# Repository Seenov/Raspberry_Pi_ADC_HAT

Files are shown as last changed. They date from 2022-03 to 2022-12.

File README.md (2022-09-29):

# 6 Channel ADC Hat for Raspberry Pi
Wi-Fi hat with ESP32

For the Raspberry Pi install node-red with version 16 of Nodejs and upload the flow file  "ADC1-esp32c3rev3_2.json" in this root directory. 
The flow file  "ADC1-esp32c3rev3_1.json" works with networks of 512 ip addresses. x.x.0.0 to x.x.1.255 Comment-out line 15 of the "set broadcast ip" node to work with networks of 255 ip addresses.
The list of dependencies for this project are in the file "packages.json"

For Arduino use the sketch in the directory  "RPI_ADC_Hat_analognwifi_rev1"
In the root directory the file "esp32c3setup arduino" show the setting under Tools in the arduino IDE (1.8.16)
The ino file rev2 introduces a self-test feature we use to ensure each unit is functionning properly. DO NOT USE THIS VERSION
The .ino file rev3 is used to test communications with a python script. There is an issue with UDP port usage with this version. It transmitts its messages on port 50450 instead of 5045. It listens on port 5044.

<b>Documentation</b>

<a href="https://seenov.com/2022/03/14/getting_started_6_channel_esp32c3_adc/"><b>Getting </b><b>S</b><b>tarted</b></a>

<a href="https://seenov.com/wp-content/uploads/2022/03/ESP32C3-ADC-hat-specifications.pdf">Specifications</a>

<a href="https://seenov.com/2021/12/15/raspberry-pi-adc-esp32-hat-incredibly-measures-%C2%B112v-with-great-accuracy/">Configuring ADC inputs</a>

<b>Explainer videos Seenov YouTube channel</b>

<a href="https://www.youtube.com/channel/UC92-OhJZzrrUEJLgdM26cIA"> Seenov YouTube Channel</a>

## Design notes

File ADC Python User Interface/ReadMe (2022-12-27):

#################   INSTRUCTIONS  #################
Required files (all in same directory):
ADC_UI_Beta1.py
MQueues.py
_support_Beta1.py
Threads.py

Install CustomTkInter  link: https://github.com/TomSchimansky/CustomTkinter
pip3 install customtkinter
A copy of the customtkinter folder from the Github repository is placed in the 
same folder as this script in case you cannot use pip3

-  Connect power to the  ESP32C3 ADC Hat and wait for the Green LED to turn on.
-  The ADC will be in Hotspot mode. Using a WiFi enabled device, phone, tablet
   or Raspberry Pi. Connect to the Network ADC_xxx, xxx is part of the mac address
   of the ADC. Ignore no Internet messages.
-  Navigate to the Page 192.168.4.1  and enter the SSID and Password of your WiFi
-  The ADC will reboot and the green LED will turn off. If not, retry the previous steps.
-  Run the ADC_UI_Beta1.py python script. A control panel window will open in the center of the screen.
-  The scrit should find the ADC. Enable the ADC channels and you should see the voltages
   being displayed.
   
- Known issues: at startup ADC ch 0 may display a previous value instead of 0 mV
                Sliders are not very responsive on Raspberry PI computers.
                The Seenov Logo is not displayed

-  Find more information at www.seenov.com
-  email us at info@seenov.com for support.

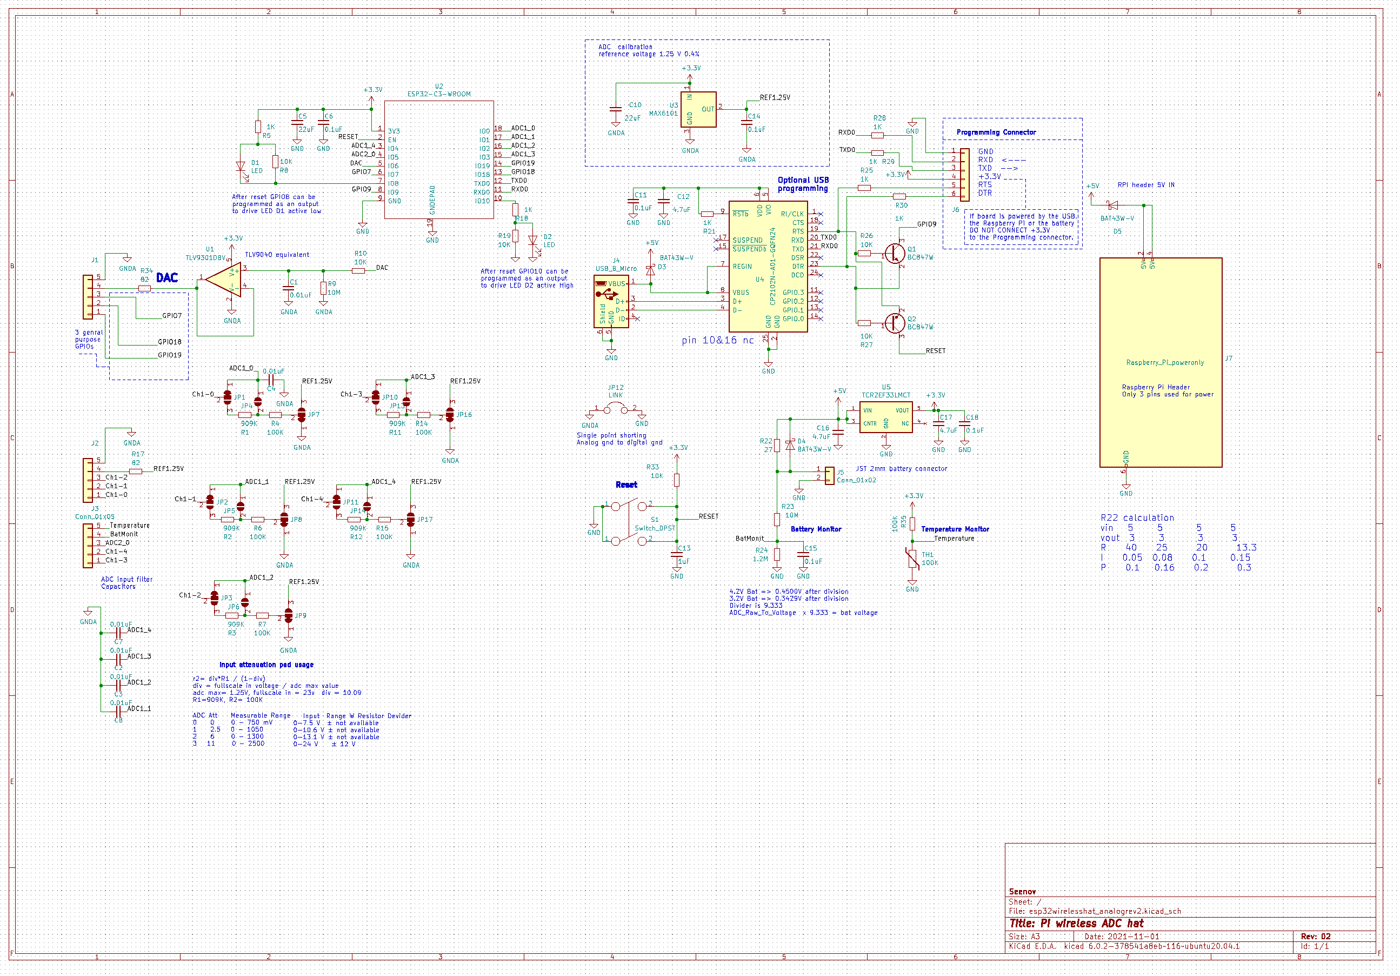
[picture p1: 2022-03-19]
ESP32C3 Raspberry Pi 6 channel ADC Hat Schematicv2.png

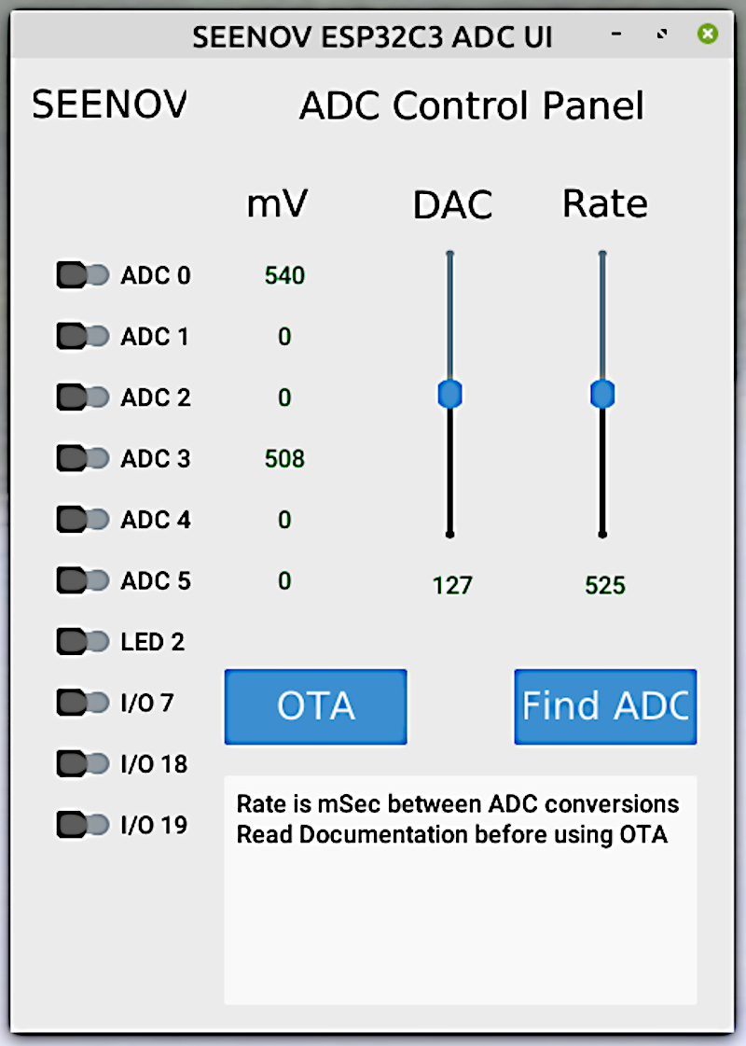
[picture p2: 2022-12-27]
ADC Python User Interface/ADC Python UI1.png

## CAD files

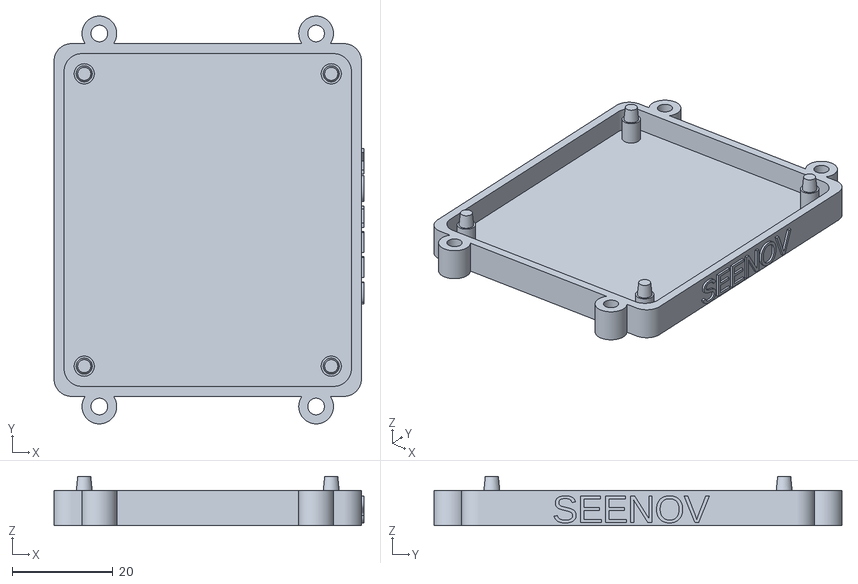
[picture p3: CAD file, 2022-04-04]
OpenScad 3D models/esp32ADC_opencase.stl
61.5 x 80.9 x 9.78

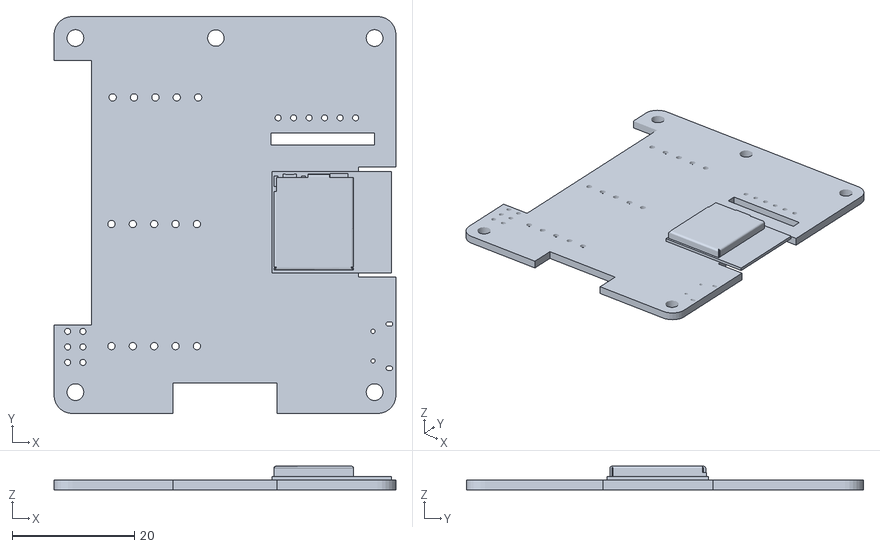
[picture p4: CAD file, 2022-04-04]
OpenScad 3D models/adc.stl
56.0 x 65.0 x 3.93

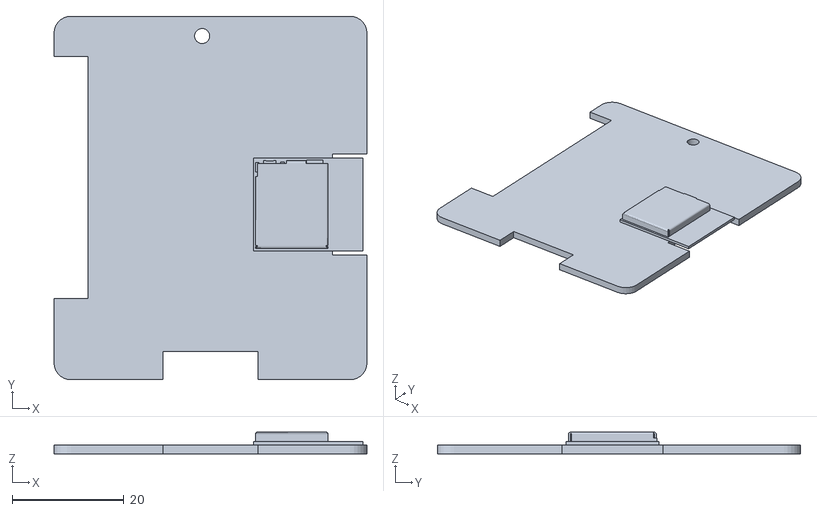
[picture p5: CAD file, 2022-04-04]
OpenScad 3D models/adc2a.stl
56.0 x 65.0 x 3.93

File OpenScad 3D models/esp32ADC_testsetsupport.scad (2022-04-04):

$fn=90;
//include <threads.scad>;
include </home/claudea2/Dropbox/3D printer/openscad_primitives-master/fillet_cube.scad>;
// rev 4 2 slots, 3.5mm instead of 5mm long
overlap =5;
len2 = 10;
len3= 5.16;
len4= 8.9;
diam1= (3.7*25.4)+2.4;
diam2= 5*25.4;  //  was 6*25.4;
ventholesdiam =3;
diam3= 13.6;
diam4= 9.6;
glassdiam=200;
fandiam=120;
largewall=3.2;
smallwall = 1.6;
 baseholediam= 6;
totallen = 104.6;
 pindiam=1.65;  // pogo pin holder diampindiam 1.3 bump 1.5
  wirechannel=1.6;
pcbwidth=40.5;
offx=65;
offy=93.6;
coin1x= -16.9;
coin1y = -65.47;
coin2x= 49;
coin2y = 0;
coin3x= 49;
coin3y = -58;
coin4x=  0;
coin4y= -58;
adcx=56.02  ;
adcy= 65.03;
pin=2.75; //  mounting hole in pcb
pogo1x=-1.27;  //2.54mmx2
pogo1y=4.87;
pogo2x=5.9;  // 3.5mm
pogo2y=7.53;
pogo3x=5.9;
pogo3y=27.53;
pogo4x=6.1;
pogo4y=48.28;
pogo5x=33.2; // 2.54mm
pogo5y=44.93;
screwhole= 3.0;
// pogo IDI   R-1-SC/RSS-75-SC
// receptacle  S-1-E-3.8-G


pogoheight = 6.59 +2.5;
pcbsspacer = 8.64+4.57-1.78-5; // 11.43
pcbheight=178;
pcbthick= 1.6;
//height above PCB
height4= pogoheight+pcbthick;
// for test add 10mm    
len1 = 10 + totallen - len2 -len3 -len4 +overlap;
 fit=0.6; 
mountingspherediam=3;
// measuring tool
//translate([52.5,0,-26]) cube([1,105,1],center=true);
//show = 0;
//show="PCBClips"; // ,   "    " ,       "    ";// "fan";
//show="mount";  // hanging mount
//show="topbox";
//show = "fan";
//show = "PCBBaseclip";

// uncomment to see

//selector ="main";
//selector ="base";

//selector ="push";
//selector = "bolt";
//selector = "tb";
//selector ="break";
selector = "case";
/*********************************************************
*
*        Pogo test jig for ADC rev 2
*
*
**************************************************************/



//color( "Aqua", 1.0 )translate([offx+coin1x,coin1y-offy,pcbsspacer])  import("adc.stl", convexity=3);
module mainpin(){
 // main body above z=0
difference(){
// base cube    
translate([-8,-8,0])  cube([67,75,5]) ;
    
 // larger cut-out for better fit 
translate([-6,-6,-0.05])  cube([adcx+6,adcy+6,8.1]) ;
}
// round corner for better printing
  translate([-6,-6,-7.9])   cylinder(d=8,h=13-0.1);
translate([adcx,-6,-7.9])   cylinder(d=8,h=13-0.1);
translate([-6,+adcy,-7.9])   cylinder(d=8,h=13-0.1);
translate([adcx,+adcy,-7.9])   cylinder(d=8,h=13-0.1);
// space for align pins pcb at correct height
translate([0,0,-0.1]) alignpins(4,4,pcbsspacer);
// Align pins
translate([0,0,pcbsspacer-0.1]) alignpins(2.4,2,4.5);
// base pogo receptacle fit into base
difference(){
translate([-8,-8,-7.9])  cube([67,75,8]) ;
 translate([0,0,-8])    pinholes(10);
}
// align pins
module alignpins(dd1,dd2,hh){
translate([0,0,0])   cylinder(d1=dd1,d2=dd2,h=hh);
translate([coin2x,coin2y,0])  cylinder(d1=dd1,d2=dd2,h=hh);
translate([coin3x,-coin3y,0])  cylinder(d1=dd1,d2=dd2,h=hh);
translate([coin4x,-coin4y,0])  cylinder(d1=dd1,d2=dd2,h=hh);
}
module pinholes(hh){
for(yi =[pogo1y:5.08:pogo1y+5.08]) translate([pogo1x,yi,0]) cylinder(d=pindiam,h=hh);
for(xi =[pogo5x:2.54:pogo5x+(5*2.54)]) translate([xi,pogo5y,0]) cylinder(d=pindiam,h=hh);
    
for(xi =[pogo2x:3.5:pogo2x+(4*3.5)]) translate([xi,pogo2y,0]) cylinder(d=pindiam,h=hh);
for(xi =[pogo3x:3.5:pogo3x+(4*3.5)]) translate([xi,pogo3y,0]) cylinder(d=pindiam,h=hh);
for(xi =[pogo4x:3.5:pogo4x+(4*3.5)]) translate([xi,pogo4y,0]) cylinder(d=pindiam,h=hh);
}
 
}
module base2(){
// bottom base
translate([0,0,15])difference(){
translate([-8-4,-8-4,-40])  cube([67+8,75+8,25]) ;
translate([-8,-8,-40+4])  cube([67,75,30]) ;
translate([-6-33/2,-6-34/2,-41])   cube([33,34,30]);
translate([adcx-33/2,-6-34/2,-41])   cube([33,34,30]);
translate([-6-33/2,+adcy-34/2,-41])   cube([33,34,30]);
translate([adcx-33/2,+adcy-34/2,-41])   cube([33,34,30]);
}
// holder for pushdown
translate([-55,18,-25])  cube([44,25,10]) ;
difference(){
translate([-55,30,-25])  cube([12,12,35]) ;
translate([-46,50,6]) rotate([90,0,0])   cylinder(d=screwhole+0.3, h=50);  
translate([-52,50,6]) rotate([90,0,0])   cylinder(d=screwhole+0.3, h=50);      
}
// tye point spring
difference(){
translate([-25,24,-25])  cube([8,6,15]) ;
translate([-21,50,-12.5]) rotate([90,0,0])   cylinder(d=screwhole, h=50);  
}     
}


if (selector =="main"){
difference(){
      mainpin();
     translate([26,79,-4]) rotate([90,0,0])   cylinder(d=screwhole, h=100);
     translate([-26,-6+79/2,-4]) rotate([90,0,90])   cylinder(d=screwhole, h=100);
  
}
}

if (selector =="base"){
difference(){
      base2();
     translate([26,79,-4]) rotate([90,0,0])   cylinder(d=screwhole+0.5, h=100);
     translate([-26,-6+79/2,-4]) rotate([90,0,90])   cylinder(d=screwhole+0.5, h=100);
  
}
}
if (selector =="push"){

pushdown();
}
// push down
module pushdown(){
 translate([-11,0,0])difference(){
 translate([0,0,0]) rotate([0,0,0])   cylinder(d=76, h=10);
 translate([0,0,-0.1]) rotate([0,0,0])   cylinder(d=61, h=11);
  translate([0,-25,5.5])  cube([100,50,12],center=true);   
    translate([-34,4,-1]) rotate([0,0,0])   cylinder(d=screwhole+0.3, h=20);
    
}
 // lever
    translate([-20,8,0]) rotate([0,0,-2])   cube([150,25,10]);  
}


// bolt holder
if (selector =="bolt"){
    bolt();
}

/******************************************************
*
*   replace a centered square cube with a rounded cube
*
*
************************************************************/
module roundedcube(xx,yy,zz,rr){
    translate([(-xx+(2*rr))/2,(-yy+(2*rr))/2,-zz/2]) minkowski()
{
  cube([xx-(2*rr),yy-(2*rr),zz-1]);
  cylinder(r=rr,h=1);
}
}

if (selector =="break"){
    difference(){
         cube([30,20,12],center=true); 
        translate([0,0,6-2.4])   cube([54,2,5],center=true); 
    }
    translate([0,0,-50-5.5])     cylinder(d=20, h=50);
}


module bolt(){
    
 /*  translate([-(58-2)/2,-(28-2)/2,-5]) minkowski()
{
  cube([60-4,30-4,10-1]);
  cylinder(r=2,h=1);
}
*/
    difference(){
         roundedcube(60,30,10,2); 
        translate([0,0,-0.1])   cube([10.5,10.5,12],center=true);  
        translate([0,0,-0.1])     cylinder(d=22, h=6.5);
        translate([30-6,15-6,-7])     cylinder(d=4, h=14);
        translate([30-6,-15+6,-7])     cylinder(d=4, h=14);
        translate([-30+6,15-6,-7])     cylinder(d=4, h=14);
        translate([-30+6,-15+6,-7])     cylinder(d=4, h=14); 
    }
    
    translate([0,40,0]) difference(){
         roundedcube(40,30,10,2);  
         translate([10,0,-6.1])cylinder(d=9.7, h=12);
    }
  
}
if (selector=="case"){
    casey=66;
    casex=57;
  translate([casex/2-4,casey/2-4,2])  difference(){
         roundedcube(casex+4,casey+4,7,3.5); 
        translate([0,0,2])  roundedcube(casex,casey,7,3.5); 
    } 
 
// space for align pins pcb at correct height
translate([0,0,-0.1]) alignpins2(4,4,pcbsspacer-1);
// Align pins
translate([0,0,pcbsspacer-1.15]) alignpins2(3.2,2.6,3);
    // bumps
    /*
        translate([0,0,pcbsspacer+1])   sphere(d=2.7);
translate([coin2x,coin2y,pcbsspacer+1])  sphere(d=2.7);
translate([coin3x,-coin3y,pcbsspacer+1])  sphere(d=2.7);
translate([coin4x,-coin4y,pcbsspacer+1])  sphere(d=2.7);
    */
// mounting holes
   translate([3,-8,-1.5]) holeD(3.3,7,3.3+1.8+1.8);
   translate([3,+casey,-1.5]) holeD(3.3,7,3.3+1.8+1.8);
translate([casex-8-3,-8,-1.5]) holeD(3.3,7,3.3+1.8+1.8);
   translate([casex-8-3,+casey,-1.5]) holeD(3.3,7,3.3+1.8+1.8);
// text
    
 translate([casex-2.5,12,-0.9])   rotate([90,0,90]) linear_extrude(1,convexity=1)text(size=5.5,"SEENOV");
}
// align pins
module  alignpins2(dd1,dd2,hh){
translate([0,0,0])   cylinder(d1=dd1,d2=dd2,h=hh);
translate([coin2x,coin2y,0])  cylinder(d1=dd1,d2=dd2,h=hh);
translate([coin3x,-coin3y,0])  cylinder(d1=dd1,d2=dd2,h=hh);
translate([coin4x,-coin4y,0])  cylinder(d1=dd1,d2=dd2,h=hh);

}
/***************************************************************
*            holder for terminal blocks
*
****************************************************************/
if (selector =="tb"){
     difference(){
         roundedcube(17.5+10,10+6,4,1); 
         translate([0,0,-0.1])  cube([17.5,10,6],center=true); 
         translate([-2.5+(17.5+10)/2,0,-6])     cylinder(d=3.3, h=12);
         translate([-(-2.5+(17.5+10)/2),0,-6])     cylinder(d=3.3, h=12);
     }
     for (i = [0,7,-7]) { 
         translate([i,5,2-(1.64/2)]) sphere(d=0.8); 
         translate([i,-5,2-(1.64/2)]) sphere(d=0.8); 
         } 
         translate([-2.5+(17.5+10)/2,0,1.9])  holeD(3.3,8,3.3+1.7);
         translate([-(-2.5+(17.5+10)/2),0,1.9])  holeD(3.3,8,3.3+1.7);
}


//    *******************************************************
// old design no longer used
//
//
//  *********************************************************
 module mainBody(){

  
//translate([-7.29,-8.31,1.5+8])color( "Aqua", 1.0 ) import("FH1.stl", convexity=3);
 
//***************************
// rectangle holder
//***************************
yy=55+0.4;
xx=64.4+0.4;
thick1=4.7;
standoffheight=pogoheight;
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

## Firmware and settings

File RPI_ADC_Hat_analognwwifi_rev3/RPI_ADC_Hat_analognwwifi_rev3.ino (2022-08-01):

/*
 * MIT License

Copyright (c) [2022] [Seenov inc.]

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
THE SOFTWARE IS PROVIDED "AS IS", WITHOUT WARRANTY OF ANY KIND, EXPRESS OR
IMPLIED, INCLUDING BUT NOT LIMITED TO THE WARRANTIES OF MERCHANTABILITY,
FITNESS FOR A PARTICULAR PURPOSE AND NONINFRINGEMENT. IN NO EVENT SHALL THE
AUTHORS OR COPYRIGHT HOLDERS BE LIABLE FOR ANY CLAIM, DAMAGES OR OTHER
LIABILITY, WHETHER IN AN ACTION OF CONTRACT, TORT OR OTHERWISE, ARISING FROM,
OUT OF OR IN CONNECTION WITH THE SOFTWARE OR THE USE OR OTHER DEALINGS IN THE
SOFTWARE.
 * */

/*Program & Source Code:  6 Channel Raspberry Pi ADC with ESP32C3
  The Program is designed to follow the below steps.

  On First boot, the ESP32C3, in Station mode, will read the pre-registered SSID and password combination and try to connect to the same.

  If this process fails, it sets the ESP32C3 into AccessPoint mode and creates an open WiFi(Not protected with Password);

  This open WiFi will allow the user to connect Using any Wi-Fi enabled device with a browser. the SSID is ADC_xxyyzz xx-zz last 3 mac adress digits.

  After establishing a connection with the AccessPoint, you can go to the default IP address 192.168.4.1 to open a web page that allows you to input the SSID and password of your network;

  Once a new SSID and password is programmed into the EESP32C3's eeprom, the ESP32C3 reboots and tries to connect to your network;

  If it establishes a connection, the process is completed successfully. 

  If the connection fails again, it will restart the process.

  Once connected it waits for UDP messages from a Raspberry Pi running Node-Red. The UDP ports used are: send port 5045   receive on port 5044. 
  
  In Node-Red a broadcast UDP message is sent. The EESP32C3 ADC responds with its IP address enabling Node-Red to establish a one-on-one communication channel.

  The  ESP32C3 ADC and Node-Red exchange json encoded messages. 
   
Json messages from Node-Red
init Message
device1={type:"ADC1",ip:"0.0.0.0",name:"new module",category:"init",ch0:0,ch1:0,ch2:0,ch3:0,ch4:0,ch5:0,out1:0,out2:0,out3:0,link:"down"};

settings Message
{type: "ADC1",
name: "Mydev",
category: "setting",
ench0: 100,
ench1: 100,
ench2: 100,
ench3: 100,
ench4: 100,
ench5: 99,
delay: 100,
ota: 10,
dac: 0,
led2: 0,
io7: 1,
io18: 1,
io19: 1}


The ESP32C3 Raspberry Pi 6 Channel ADC has an Over-The_Air function built in. In response to a message from Node-Red the ESP32C3 
will again turn itself into an AccessPoint. You can login and select the new firmware .bin file to upload to the ESP32C3 ADC. 
Make sure you include this functionality in any new code or you will have to used a USB to serial adaptor to reprogram the ESP32C3 ADC.

Adding self test
Revision 2.0
   
*/


/*************************************************************
 *  for info
 *  /* Definitions for error constants. 
#define ESP_OK          0       /*!< esp_err_t value indicating success (no error)
#define ESP_FAIL        -1      /*!< Generic esp_err_t code indicating failure 
#define ESP_ERR_INVALID_ARG         0x102   /*!< Invalid argument 
#define ESP_ERR_INVALID_STATE       0x103   /*!< Invalid state 
#define ESP_ERR_INVALID_SIZE        0x104   /*!< Invalid size 
#define ESP_ERR_NOT_FOUND           0x105   /*!< Requested resource not found 
#define ESP_ERR_NOT_SUPPORTED       0x106   /*!< Operation or feature not supported 
#define ESP_ERR_TIMEOUT             0x107   /*!< Operation timed out
#define ESP_ERR_INVALID_RESPONSE    0x108   /*!< Received response was invalid
 * 
 **************************************************************/
#include <WiFi.h>
#include <HTTPClient.h>
#include <EEPROM.h>
#include <WiFiClient.h>
#include <WiFiAP.h>
#include <WebServer.h>
#include "AsyncUDP.h"
//#include <AsyncTCP.h>
#include <ESPmDNS.h>
#include "ArduinoJson.h"
//#include <NoDelay.h>
#include <Update.h>
#include <esp32-hal-adc.h>
#include <Arduino.h>
#include "esp_adc_cal.h"
#include <stdio.h>
#include <stdlib.h>
#include "esp_log.h"
#include "freertos/FreeRTOS.h"
#include "freertos/task.h"
#include "driver/adc_common.h"
#include <Update.h>
#include <stdio.h>
#include <stdlib.h>
#include "esp_log.h"
#include "freertos/FreeRTOS.h"
#include "freertos/task.h"
#include "driver/adc_common.h"
//=================================

//Variables
uint8_t i = 0;

uint8_t LED_state = 1;
uint8_t AccesPointMode = 0;
uint8_t testBufffer[8] = {1, 1, 1, 1, 1, 1, 1, 1};
char channel_number;
int chan_enable[6]= {1,1,1,1,1,1};
char NumOfSamples_per_Avrg[6]={16,16,16,16,16,16};
int  msBetweenSamples[6]={50,0,0,0,0,0};
int  chan_att[6];
int  chan_coversionResults[6];
int adc_raw[6]={0,0,0,0,0,0};
int  chan_avrgResults[6]={0,0,0,0,0,0};
char counting[6] = {0, 0, 0, 0, 0, 0,};
const int test_avrg_results_high[6]={1038,827,623,417,208,802};
const int test_avrg_results_low[6]={1020,812,605,400,193,725};
double  chan_summ[6];
char channelToRead = 0;
char ADC2_ch0_samples=0;
char do_once=0;
int statusCode;
int ij=0;
int DAC_setting=0;
const char* ssid = "ASUS24";
const char* password = "Seenovtest";
String localwifissid= "ASUS24"; // for test
String localwifipsw= "Seenovtest";
String st;
String content;
String esid;
String hostname = "esp32c3_adc";
const char* host = "esp32c3_adc";
String epass = "";
char rebootNow = 0;
String selfTest ="";
char iotest1=0;
char iotest2=0;
char iotest3=0;
char iotest4=0;
int selfTestResults=0;
char softReboot = 0;
byte mac1[6];
char newssid[] = "ADC_123456";
char UDP_ch_active =0;
char ascii_mac[19] = {};
char temp_string[255] = {};
String testmac = "3c:61:05:0c:85:a0";
IPAddress ReceivedFromIP;
IPAddress ip;

/**************************************
 * Decremented in interval 3 20000 = 2000 sec.
 *  Turns off Serial.Print where not needed
 ***************************************/
int verbosePrint= 40000;
     
#define INTERVAL_1 5000
#define INTERVAL_2 3000   // adc2_0  low priority slow signal 1 conversions every xxxx mSec
#define INTERVAL_3 100    // blinking 100 mSec, decrements verbose
#define INTERVAL_4 3000
#define GPIO_LED   8
#define GPIO_LED2  10
#define DAC        6
#define GPIO_7     7
#define GPIO_18   18
#define GPIO_19   19
int LED2_low_high = 0;
int GPIO_7_value=0;
int GPIO_18_value=0;
int GPIO_19_value=0;
//ADC Attenuation
#define ADC_ATTEN           ADC_ATTEN_DB_11
//ADC Calibration
#define ADC_CALI_SCHEME     ESP_ADC_CAL_VAL_EFUSE_TP
#define OTA_Key 1234     // key to start OTA firmware update
int OTA=0;             // value read from UDP message
StaticJsonDocument<1000> doc_r;
StaticJsonDocument<1000> doc_s;
StaticJsonDocument<1000> doc_ota;
char  fromString[210];   // for udp send
uint8_t udpString[210];  // for udp send
int SendLen;
unsigned long time_1 = 0;
unsigned long time_2 = 0;
unsigned long time_3 = 0;
unsigned long time_4 = 0;
 
 

//Function Decalration
bool testWifi(void);
void launchWeb(void);
void setupAP(void);
void blinkLED();

WebServer server(80);   // used to input network credentials and required for OTA Firmware update
AsyncUDP udp;

//====================================
/*
 * Login page for OTA required for OTA Firmware update
 */

const char* loginIndex =
 "<!DOCTYPE html> <html>  <head><meta name=  'viewport  ' content=  'width=device-width, initial-scale=1.0, user-scalable=no  '>  "
 "<title>ESP WiFi Manager</title>   <style>html { font-family: Helvetica; display: inline-block; margin: 0px auto; text-align: center;}"
 "body{margin-top: 50px;} h1 {color: #444444;margin: 30px auto 30px;}   h3 {color: #ffffff;margin-bottom: 50px;}   label{display:inline-block;width: 160px;text-align: center;font-size: 1.5rem; font-weight: bold;color: #ffffff;}"
"form{margin: 0 auto;width: 360px;padding: 1em;border: 1px solid #CCC;border-radius: 1em; background-color: #077c9f;}    input {margin: 0.5em;font-size: 1.5rem; } "
 " .styled {    border: 0;    line-height: 2.5;    padding: 0 20px;    font-size: 1.5rem;    text-align: center;    color: #fff;    text-shadow: 1px 1px 1px #000; "
 "  border-radius: 10px;    background-color: rgba(220, 0, 0, 1);    background-image: linear-gradient(to top left,  rgba(0, 0, 0, .2), rgba(0, 0, 0, .2) 30%, "
 "  rgba(0, 0, 0, 0));    box-shadow: inset 2px 2px 3px rgba(255, 255, 255, .6),   inset -2px -2px 3px rgba(0, 0, 0, .6);.styled:hover {   background-color: rgba(255, 0, 0, 1);} "
".styled:active {    box-shadow: inset -2px -2px 3px rgba(255, 255, 255, .6), inset 2px 2px 3px rgba(0, 0, 0, .6);}  </style>"  
" <meta charset=  'UTF-8  '>    </head>   <body>   <h1>Welcome to ADC1 Firmware Update</h1>    <h1>Login Page</h1> " 
"   <form name = 'loginForm' method='get' action='setting'> <div><label>Username</label> <input type ='text' name= 'userid' length= 32></div>"  
"  <div><label>Password </label> <input type = 'Password' name=  'pwd'  length= 32></div>  "
" <h3>Please Double Check Before Saving</h3>   "
"<button class= 'favorite styled ' type= 'submit' onclick='check(this.form)' value='Login'> SUBMIT</button> </form> " 

"<script>"
    "function check(form)"
    "{"
    "if(form.userid.value=='admin' && form.pwd.value=='admin')"
    "{"
    "window.open('/serverIndex')"
    "}"
    "else"
    "{"
    " alert('Error Password or Username')/*displays error message*/"
    "}"
    "}"
"</script>"
" </body>  </html> ";


/*
 * Server Index Page for OTA required for OTA Firmware update
 */

const char* serverIndex =
"<script src='https://ajax.googleapis.com/ajax/libs/jquery/3.2.1/jquery.min.js'></script>"
"<form method='POST' action='#' enctype='multipart/form-data' id='upload_form'>"
   "<input type='file' name='update'>"
        "<input type='submit' value='Update'>"
    "</form>"
 "<div id='prg'>progress: 0%</div>"
 "<script>"
  "$('form').submit(function(e){"
  "e.preventDefault();"
  "var form = $('#upload_form')[0];"
  "var data = new FormData(form);"
  " $.ajax({"
  "url: '/update',"
  "type: 'POST',"
  "data: data,"
  "contentType: false,"
  "processData:false,"
  "xhr: function() {"
  "var xhr = new window.XMLHttpRequest();"
  "xhr.upload.addEventListener('progress', function(evt) {"
  "if (evt.lengthComputable) {"
  "var per = evt.loaded / evt.total;"
  "$('#prg').html('progress: ' + Math.round(per*100) + '%');"
  "}"
  "}, false);"
  "return xhr;"
  "},"
  "success:function(d, s) {"
  "console.log('success!')"
 "},"
 "error: function (a, b, c) {"
 "}"
 "});"
 "});"
 "</script>";

static esp_adc_cal_characteristics_t adc1_chars;
static esp_adc_cal_characteristics_t adc2_chars;

static bool adc_calibration_init(void)
{
    esp_err_t ret;
    bool cali_enable = false;

    ret = esp_adc_cal_check_efuse(ADC_CALI_SCHEME);
    if (ret == ESP_ERR_NOT_SUPPORTED) {
        Serial.println( "Calibration scheme not supported, skip software calibration");
    } else if (ret == ESP_ERR_INVALID_VERSION) {
        Serial.println( "eFuse not burnt, skip software calibration");
    } else if (ret == ESP_OK) {
        cali_enable = true;
        esp_adc_cal_characterize(ADC_UNIT_1, ADC_ATTEN, ADC_WIDTH_BIT_12, 0, &adc1_chars);
        esp_adc_cal_characterize(ADC_UNIT_2, ADC_ATTEN, ADC_WIDTH_BIT_12, 0, &adc2_chars);
    } else {
        Serial.println("Invalid arg");
    }

    return cali_enable;
}
 bool cali_enable = adc_calibration_init();
//=======================================
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
void loop() {

//required for OTA Firmware update
 if ((AccesPointMode == 1) || (OTA == OTA_Key)) 
  {
   
   server.handleClient();
   
  }

 
  /****************************************
   * tbd
   * Function to force get new chredentials by software
   * Add Node-red object  that will be decoded 
   * 
   ***************************************
  if (softReboot == 1)
  {
    softReboot = 0;
    Serial.println("Turning the HotSpot On");
    setupAP();// Setup HotSpot to get new SSID and PSW
    AccesPointMode = 1;
    digitalWrite(GPIO_LED, LOW);
  }
  */
  
   /**********************************************
   *  required for OTA Firmware update
   * Function for over the air programming
   * In Node-Red push OTA button 
   * Go to web page  http://esp32c3_adc.local 
   * login user: admin psw: admin
   * 
   ***********************************************/
      if((OTA == OTA_Key) &&(do_once==0))
      {
           do_once=1;
             //use mdns for host name resolution
              if (!MDNS.begin(host)) { //http://esp32c3_adc.local
                Serial.println("Error setting up MDNS responder!");
                while (1) {
                  Serial.print("+");
                  delay(1000);
                }
              }
              server.begin();
              Serial.println("mDNS responder started");
              //return index page which is stored in serverIndex 
              server.on("/", HTTP_GET, []() {
                server.sendHeader("Connection", "close");
                server.send(200, "text/html", loginIndex);
              });
              server.on("/serverIndex", HTTP_GET, []() {
                server.sendHeader("Connection", "close");
                server.send(200, "text/html", serverIndex);
              });
              //handling uploading firmware file 
              server.on("/update", HTTP_POST, []() {
                server.sendHeader("Connection", "close");
                server.send(200, "text/plain", (Update.hasError()) ? "FAIL" : "OK");
                ESP.restart();
              }, []() {
                HTTPUpload& upload = server.upload();
                if (upload.status == UPLOAD_FILE_START) {
                  Serial.printf("Update: %s\n", upload.filename.c_str());
                  if (!Update.begin(UPDATE_SIZE_UNKNOWN)) { //start with max available size
                    Update.printError(Serial);
                  }
                } else if (upload.status == UPLOAD_FILE_WRITE) {
                  // flashing firmware to ESP
                  if (Update.write(upload.buf, upload.currentSize) != upload.currentSize) {
                    Update.printError(Serial);
                  }
                } else if (upload.status == UPLOAD_FILE_END) {
                  if (Update.end(true)) { //true to set the size to the current progress
                    Serial.printf("Update Success: %u\nRebooting...\n", upload.totalSize);
                  } else {
                    Update.printError(Serial);
                  }
                }
              });
              
            
      }

     
  
    /*****************************************************************************
    * 
    *    Create and Send udp json packet with ADC values in int32 mV format
    *    samples are averages of 16 samples  
    *    Important no output until receive from udp to find ip of destination send to
    *     json doc doc_s send. Stop if OTA is active
    *    Node-Red extracts the ip from the first of these messages
    *  
    ************************************************************************************/
    if((millis() >= time_4 + INTERVAL_4)&& (OTA != OTA_Key))
    {
        time_4 += INTERVAL_4;
        // always send all 6 channels
        doc_s["type"] = "ADC1";  //  define packet content
        doc_s["ch0"] = chan_avrgResults[0];
        doc_s["ch1"] = chan_avrgResults[1];
        doc_s["ch2"] = chan_avrgResults[2];
        doc_s["ch3"] = chan_avrgResults[3];
        doc_s["ch4"] = chan_avrgResults[4];
        doc_s["ch5"] = chan_avrgResults[5];
        // Send the data over UDP if  active
        if(UDP_ch_active==1)
        {
            serializeJson(doc_s, fromString);
            SendLen = strlen( fromString );
            memcpy( udpString, fromString, SendLen );
            if(verbosePrint)
            {
            Serial.print("sending message to: ");
            Serial.println(ReceivedFromIP);
            Serial.print("ch 0 mV: ");
            Serial.print(chan_avrgResults[0]);
            Serial.print("    ch 1 mV: ");
            Serial.print(chan_avrgResults[1]);
            Serial.print("    ch 2 mV: ");
            Serial.print(chan_avrgResults[2]);
            Serial.print("    ch 3 mV: ");
            Serial.print(chan_avrgResults[3]);
            Serial.print("    ch 4 mV: ");
            Serial.println(chan_avrgResults[4]); 
            Serial.print("    ch 5 mV: ");
            Serial.println(chan_avrgResults[5]); 
            }
            AsyncUDPMessage msg(strlen(fromString));
            msg.write( udpString, SendLen );
            udp.sendTo( msg, ReceivedFromIP, 5045 );
        }
   }
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

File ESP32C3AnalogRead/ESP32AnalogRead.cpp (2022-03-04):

/*
 * ESP32AnalogRead.cpp
 *
 *  Created on: Apr 10, 2020
 *      Author: hephaestus
 *      https://github.com/madhephaestus/ESPMutexDemo/blob/DSPTest/ESPMutexDemo.ino
*       Modified by Claude Arpin March 3, 2022
*     www.seenov.com
*   ADC2  not working possibly issue attachpin pinNUm >4 ,  5 = ADC2 channel 0
 */

#include "ESP32AnalogRead.h"

ESP32AnalogRead::ESP32AnalogRead(int pinNum) {
	if (!(pinNum < 0)) {  // attach pin 5 = ADC2 chan 0, creates reboot.
		attach(pinNum);
	}
}
void ESP32AnalogRead::attach(int pin) {
	myPin = pin;
	channel = (adc_channel_t) digitalPinToAnalogChannel(myPin);
	attached = true;
}

float ESP32AnalogRead::readVoltage() {
	int mv = readMiliVolts();

	return mv * 0.001;
}
/**
 * typedef enum {
 ADC1_CHANNEL_0 = 0, !< ADC1 channel 0 is GPIO36
 ADC1_CHANNEL_1,     !< ADC1 channel 1 is GPIO37
 ADC1_CHANNEL_2,     !< ADC1 channel 2 is GPIO38
 ADC1_CHANNEL_3,     !< ADC1 channel 3 is GPIO39
 ADC1_CHANNEL_4,     !< ADC1 channel 4 is GPIO32
 ADC1_CHANNEL_5,     !< ADC1 channel 5 is GPIO33
 ADC1_CHANNEL_6,     !< ADC1 channel 6 is GPIO34
 ADC1_CHANNEL_7,     !< ADC1 channel 7 is GPIO35
 ADC1_CHANNEL_MAX,
 } adc1_channel_t;

 typedef enum {
 ADC2_CHANNEL_0 = 0, !< ADC2 channel 0 is GPIO4
 ADC2_CHANNEL_1,     !< ADC2 channel 1 is GPIO0
 ADC2_CHANNEL_2,     !< ADC2 channel 2 is GPIO2
 ADC2_CHANNEL_3,     !< ADC2 channel 3 is GPIO15
 ADC2_CHANNEL_4,     !< ADC2 channel 4 is GPIO13
 ADC2_CHANNEL_5,     !< ADC2 channel 5 is GPIO12
 ADC2_CHANNEL_6,     !< ADC2 channel 6 is GPIO14
 ADC2_CHANNEL_7,     !< ADC2 channel 7 is GPIO27
 ADC2_CHANNEL_8,     !< ADC2 channel 8 is GPIO25
 ADC2_CHANNEL_9,     !< ADC2 channel 9 is GPIO26
 ADC2_CHANNEL_MAX,
 } adc2_channel_t;
 */
int ESP32AnalogRead::readMiliVolts() {
	if (!attached)
		return 0;
	analogRead(myPin);
	// Configure ADC
	adc_unit_t unit;
	if (myPin <5) {
		adc1_config_width(ADC_WIDTH_12Bit);
		adc1_channel_t chan= ADC1_CHANNEL_0;
		unit=ADC_UNIT_1;
		switch (myPin) {

		case 0:
			chan = ADC1_CHANNEL_0;
			break;
		case 1:
			chan = ADC1_CHANNEL_1;
			break;
		case 2:
			chan = ADC1_CHANNEL_2;
			break;
		case 3:
			chan = ADC1_CHANNEL_3;
			break;
		case 4:
			chan = ADC1_CHANNEL_4;
			break;
		
		}
		adc1_channel = chan;
		adc1_config_channel_atten(chan, ADC_ATTEN_11db);
	} else {
       // adc2_config_width(ADC_WIDTH_12Bit);
		adc2_channel_t chan= ADC2_CHANNEL_0;
		unit=ADC_UNIT_2;
		switch (myPin) {
		case 5:
			chan = ADC2_CHANNEL_0;
			break;
		}
		adc2_channel = chan;
		//adc2_config_channel_atten(chan, ADC_ATTEN_11db);  
	}
	// Calculate ADC characteristics i.e. gain and offset factors
          esp_err_t ret;
           ret = esp_adc_cal_check_efuse(ESP_ADC_CAL_VAL_EFUSE_TP);
	        esp_adc_cal_characterize(unit,
			ADC_ATTEN_DB_11,
			ADC_WIDTH_BIT_12,
			0,
			&characteristics);

    esp_err_t ret1 = ESP_OK;
	int raw = 0;
	uint32_t voltage = 0;
	// Read ADC and obtain result in mV

	if (unit == ADC_UNIT_1) {
		raw = adc1_get_raw(adc1_channel);
        voltage = esp_adc_cal_raw_to_voltage(raw, &characteristics);
        return voltage;
	} else {
	   ret1 =	adc2_get_raw(ADC2_CHANNEL_0, ADC_WIDTH_BIT_12,  &raw);
      if (ret1== ESP_OK){
              voltage =  esp_adc_cal_raw_to_voltage(raw, &characteristics);
            return voltage;
       }
        return 5000;  // means there is an error, adc2 not yet supported
	}
	
	
}

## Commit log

2022-02-16 VS code working ADC example
2022-02-26 Arduino esp32c3 parameters
    Values under tools menu for the ESP32C3 such as freq, memory size etc.
2022-02-26 Arduino sketch for ESP32 wifi ADC hat
2022-03-04 Modified version of ESP32AnalogRead for ESP32C3
    The ESP32C3 analog function in Arduino does not support calibration giving results off by more than 30%. These files are modificairon of https://github.com/madhephaestus/ESP32AnalogRead
2022-03-04 temporary fix for ADC1 calibrated results.
2022-03-10 ADC issue resolved
2022-03-10 Fixed ADC calibration and added OTA s/w update
    [RPI_ADC_Hat_analognwwifi_rev1.ino]
2022-04-04 New 3d model
    [adc.stl, adc2a.stl, esp32ADC_opencase.stl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]
2022-08-01 Python scripts for ADC control
2022-09-16 Added rev 3_2 Node-red flow
    Added a new revision of the Node-Red flow. Documented details of rev 3_1 use in large networks. Added link to Seenov YouTube channel
2022-09-16 Latest version Node-Red Flow
    Fixes issue with revision 3_1
2022-12-27 Delete ADC1_OTA_firmware_trigger.py
    A new ADC Python user interface is available with this functionality
2022-12-27 New ADC UI in Python with CustomTkinter
    Python user interface for the Raspberry Pi 6 channel ADC. Tested on Raspberry Pi, Mac, Windows 10, and Linux Mint
2022-12-27 Beta 1 release of the ADC control panel
2023-02-04 Update to OTA_ command()
    Added configmsg["category"] = "setting" needed for ADC to see OTA command
    Added display of remote ip address to facilitate logging into OTA page
